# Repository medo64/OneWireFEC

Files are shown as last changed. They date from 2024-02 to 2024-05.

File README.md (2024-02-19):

1-Wire Framework Expansion Card
===============================

Non-isolated 1-Wire master.

## Pinout

To connect to this board, one has to use a 3-pin JST XH connector. The following
table represents the pinout, pin 1 being on the left as looking into the
expansion card.

| # | Ref | Description |
|--:|:-----:|---|
| 1 | GND | Ground connection |
| 2 | DQ | Data |
| 3 | V+ | Positive voltage |

Output voltage is either 3.3V or 5V at up to 100 mA.

## LEDs

Left LED signals if serial data is received or sent.

Right LED signals if output is active and there is no fault.

---
*You can check my blog and other projects at [www.medo64.com](https://www.medo64.com/electronics/).*

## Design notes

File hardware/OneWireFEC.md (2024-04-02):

### OneWireFEC Parts

|  # | Part | RefDes  | Preferred Part Number |
|---:|---|---|---|
|  4 | C 100nF X7R 16V (0805) | C1-C4 | 478-5311-1-ND |
|  3 | C 1uF 16V X7R (0805) | C5-C7 | 1276-6470-1-ND |
|  2 | C 10uF X5R 16V (0805) | C8-C9 | 1276-1096-1-ND |
|  2 | DS LED (0805) | DS1-DS2 | 475-1415-1-ND |
|  1 | J USB C, plug, straddle 0.8mm | J1 | WM12855-ND |
|  1 | J JST XH Vertical (3w) | J2 | 455-B3B-XH-A-ND |
|  1 | L Ferrite 120R@100Mhz | L1 | 240-2383-1-ND |
|  2 | R 1K 0.125W (0805) | R1-R2 | RMCF0805FT1K00CT-ND |
|  2 | R 3.3K 0.125W (0805) | R3-R4 | RMCF0805FT3K30CT-ND |
|  1 | R 5.1K 0.125W (0805) | R5 | RMCF0805FT5K10CT-ND |
|  1 | U PIC16F1454 (SOIC-14) | U1 | PIC16F1454-I/SL-ND |
|  1 | U DS2482S-100+ (SOIC-8) | U2 | DS2482S-100+-ND |
|  1 | U MIC2091-1YM5-TR (SOT23-5) | U3 | 576-3891-1-ND |
|  1 | VR MCP1700 (SOT23-3) | VR1 | MCP1700T3302ETTCT-ND |
|  2 | H Screw M2x3mm | - | - |

#### Board Size

| | Dimensions | Area | Thickness |
|---|---|---|---|
| PCB |  24.0 x 27.9 mm | 1.1 in² | 0.8 mm |

#### Specification

| | Minimum | Typical | Maximum |
|---|---:|---:|---:|
| Input voltage:  | | 5.0 V | |
| Input current:  | |  200 mA | |
| Output voltage: |  4.75 V | 5.0 V |  5.25 V |
| Output voltage: |  3.15 V | 3.3 V |  3.45 V |
| Output current: | 90 mA |  100 mA |  110 mA |

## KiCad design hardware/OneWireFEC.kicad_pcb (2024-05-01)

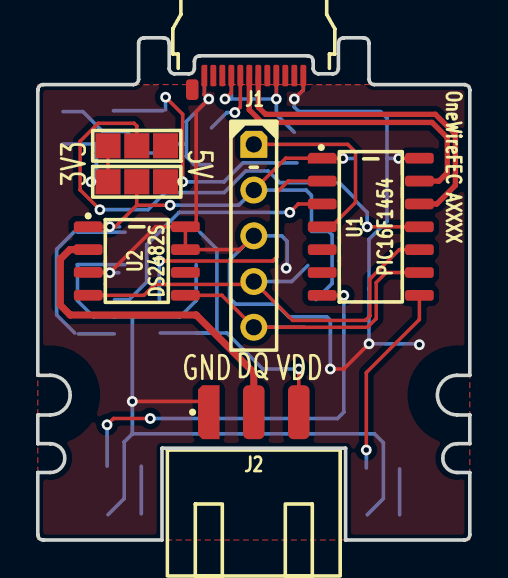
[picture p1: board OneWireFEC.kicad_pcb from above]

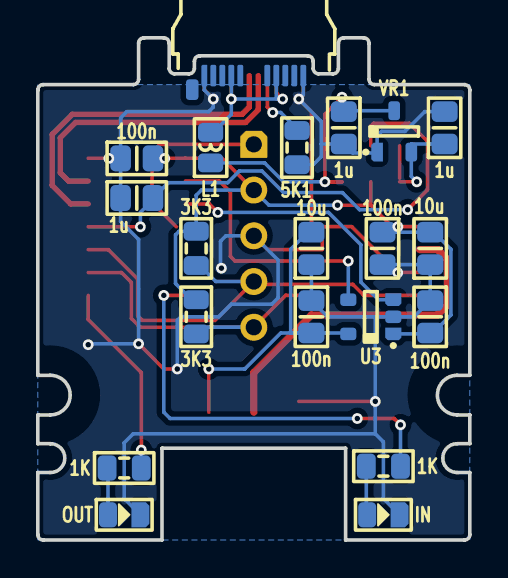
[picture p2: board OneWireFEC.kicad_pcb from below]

Board: 2 copper layers, 24.0 x 27.9 mm, 26 parts (19 on the bottom side), 20 nets.

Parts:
C1, C2, C3, C4: 100n; C (0805)
C5, C6, C7: 1u; C (0805)
C8, C9: 10u; C (0805)
DS1: IN; DS (0805)
DS2: OUT; DS (0805)
ICSP: Microchip PIC; ICSP PIC Pogo (5w)
J1: 105444-0001; J USB C 3.2 Edge (24w)
J2: B2B-XH-A; J JST XH Edge [1WIRE] (3w)
JP1, JP2: Jumper; JP Dual (1205)
L1: 120R; L (0805)
R1, R2: 1K; R (0805)
R3, R4: 3K3; R (0805)
R5: 5K1; R (0805)
U1: PIC16F1454; U Micro [PIC16F1454] (SOIC-14)
U2: DS2482S; U Transceiver 1Wire [DS2482S-100+] (SOIC-8)
U3: MIC2091; U LoadSwitch 100mA [MIC2091-1] (SOT23-5)
VR1: MCP1700; VR Linear 3.3V 250mA [MCP1700] (SOT-23)

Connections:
3V3: C7.2, JP1.1, JP2.3, VR1.2
3V3_USB: C5.1, JP2.2, U1.11
5V: C6.2, JP1.3, L1.2, VR1.3
A_CC: J1.A5, R5.2
DQ: J2.2, U2.2
GND: C1.2, C2.1, C3.2, C4.2, C5.2, C6.1, C7.1, C8.2, C9.2, DS1.1, DS2.1, ICSP.3, J1.A1, J1.A12, J1.B01, J1.B12, J2.1, R5.1, U1.14, U2.3, U2.7, U2.8, U3.2, VR1.1
ICSP_VPP: ICSP.1, U1.4
LED_A: R1.1, U1.7
LED_A': DS1.2, R1.2
LED_B: R2.1, U1.8
LED_B': DS2.2, R2.2
POWER_EN: U1.3, U3.3
POWER_FAULT: U1.2, U3.4
SCL: ICSP.4, R3.1, U1.10, U2.4
SDA: ICSP.5, R4.1, U1.9, U2.5
USB_DM: J1.A7, U1.12
USB_DP: J1.A6, U1.13
VDD: C1.1, C2.2, C3.1, C8.1, ICSP.2, JP1.2, R3.2, R4.2, U1.1, U2.1, U3.1
VDD_OUT: C4.1, C9.1, J2.3, U3.5
Vin: J1.A4, J1.A9, J1.B04, J1.B09, L1.1

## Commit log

2024-02-19 Initial version
    [OneWireFEC.kicad_pcb]
2024-02-19 Added pull-up resistors for I2C and added Vusb3V3 jumper
    [OneWireFEC.kicad_pcb]
2024-02-20 Fixed a few typos
    [OneWireFEC.kicad_pcb]
2024-04-02 Changed connector name
2024-04-18 Added output labels
    [OneWireFEC.kicad_pcb]
2024-05-01 Upgraded to KiCAD 8
    [OneWireFEC.kicad_pcb]
2024-05-01 Adjusting solder-on jumpers to be more symetric
    [OneWireFEC.kicad_pcb]
